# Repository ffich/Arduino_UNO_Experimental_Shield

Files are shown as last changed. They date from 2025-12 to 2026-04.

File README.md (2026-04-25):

# Arduino_UNO_Experimental_Shield
Experimental shield for Arduino UNO form factor boards.

Welcome to the official repository of the **UNO Experimental SHIELD**, an expansion board designed to provide a complete laboratory environment for experimenting, testing, and learning with the Arduino UNO Boards (e.g **UNO Q**).
This shield integrates digital and analog I/O, SPI, I2C, sensors, memory, and diagnostics to create a versatile platform ideal for rapid prototyping, debugging, and education.



---

## 🚀 Key Features

### 🔹 Digital I/O
- SMD LEDs on pins **D2, D3, D6, D7, D8, D9**
- Push buttons on pins **A2, A3**

### 🔹 Analog Inputs
- **Two 100 kΩ trimmers** on analog inputs **A0, A1**  

### 🔹 Serial Communication
- **USB-to-Serial bridge** (CH340)  

### 🔹 CAN Bus
- **CAN transceiver** (TJA1051T3)  
- **120 Ω termination resistor** enabled by jumper  
- Screw terminal output: CANH / CANL

### 🔹 RS-485
- **RS485 transceiver**
- **120 Ω termination resistor** enabled by jumper  
- Screw terminal output: A / B 

### 🔹 I2C Display
- Integrated **SSD1306 OLED display**

### 🔹 I2C Thermometer
- Integrated **TMP102 thermo**  

### 🔹 SPI Memory
- **25LC256 EEPROM** connected to hardware SPI  
- Dedicated Chip Select line

### 🔹 Crypto Chip
- Integrated **ATECC608C**  - 

---

## 📐 Pinout Summary

### Digital I/O
| UNO Pin | Shield Function |
|---|---|
| D2, D3, D6, D7, D8, D9 | LED  |
| A2, A3 | Buttons  |

### Analog
| Pin | Function |
|-----|---|
| A0 | Trimmer 1 |
| A1 | Trimmer 2 |

### Peripherals
| Function | Pin |
|---|-----|
| SPI EEPROM | MOSI / MISO / SCK + CS |
| I2C OLED | SDA / SCL |
| I2C Thermo | SDA / SCL |
| I2C Crypto Chip | SDA / SCL |
| CAN | CAN_TX / CAN_RX |
| RS485 | TX / RX |
| USB-Serial | TX / RX |

The Shield is compatible with both Arduino UNOs with 3V3 and 5V logic (some jumpers allow to adapt the voltage levels).

---

## 🛠️ Project Goals

This shield is intended for:
- Users who want a **complete test environment** for Arduino UNO Boards (e.g. **UNO Q**, **UNO R4**) 
- Makers performing **rapid firmware debugging**  
- Schools, workshops, and educational labs  
- Testing all core firmware interfaces (PWM, ADC, SPI, I2C, CAN, UART)

---

## 📷 Logo

The official project logo is available in the `/assets/logo/` directory.

---

## 📝 License

This project is released under the **MIT License**, unless otherwise specified for hardware files.

---

## 🤝 Contributing

Pull requests and issues are welcome!  
Contributions improving documentation, firmware examples, or hardware design are highly appreciated.

---

## 📫 Contact

For questions or suggestions, open an Issue in the repository or contact the maintainer.

---

Happy experimenting! 🔧✨

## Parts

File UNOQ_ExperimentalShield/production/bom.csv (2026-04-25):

Designator | Footprint | Quantity | Value | LCSC Part #
C1, C2, C3, C4, C5, C6, C7 | 0402 | 7 | 100nF | C155422
CN1 | PinHeader_1x02_P2.54mm_Vertical | 1 | 485 | C5360898
CN2 | USB_C_Receptacle_HRO_TYPE-C-31-M-12 | 1 | USB | C165948
CN3 | TerminalBlock_Phoenix_MPT-0,5-2-2.54_1x02_P2.54mm_Horizontal | 1 | Can | C474920
CN4 | PinHeader_1x04_P2.54mm_Vertical | 1 | Can | C2905435
CN5 | TerminalBlock_Phoenix_MPT-0,5-2-2.54_1x02_P2.54mm_Horizontal | 1 | 485 | C474920
JP1, JP2, JP3, JP4, JP6, JP7, JP8 | PinHeader_1x03_P2.54mm_Vertical | 7 | Jmp | C49257
JP5 | PinHeader_2x02_P2.54mm_Vertical | 1 | Jmp | C32713275
LD1, LD2, LD3, LD4, LD5, LD6 | 0603 | 6 | O1_G | C12624
LD10, LD8 | 0603 | 2 | Tx | C2286
LD11 | 0603 | 1 | 3v3 | C2286
LD12 | 0603 | 1 | 5v | C2286
LD7, LD9 | 0603 | 2 | Rx | C2286
OLED1 | OLED096 | 1 | OLED | C5248080
R1, R2, R3, R4, R5, R7 | 0402 | 6 | 1.5k | C25867
R10, R18, R19, R21, R22, R24, R9 | 0402 | 7 | 10k | C174175
R13, R14 | 0402 | 2 | 5.1k | C25905
R15, R16, R25, R28, R29, R30 | 0402 | 6 | 1k | C140196
R23, R27 | 0603 | 2 | 120 | C177328
R6, R8 | 0603 | 2 | 2.2k
RV1, RV2 | Potentiometer_Bourns_3386P_Vertical | 2 | Tr | C116303
SW1, SW2 | SW_SPST_PTS810 | 2 | Usr1 | C221895
U1 | SO-8_3.9x4.9mm_P1.27mm | 1 | 25LCxxx | C84670
U2 | SOT-563 | 1 | TMP102xxDRL | C99269
U3 | SOIC-8_3.9x4.9mm_P1.27mm | 1 | MAX3485ESA-MS | C7434431
U4 | JEITA_SOIC-8_3.9x4.9mm_P1.27mm | 1 | CH340N | C2977777
U5 | SOIC-8_3.9x4.9mm_P1.27mm | 1 | TJA1051T-3 | C38695
U7 | SOIC-8_3.9x4.9mm_P1.27mm | 1 | ATECC608A-SSHDA | C28975195

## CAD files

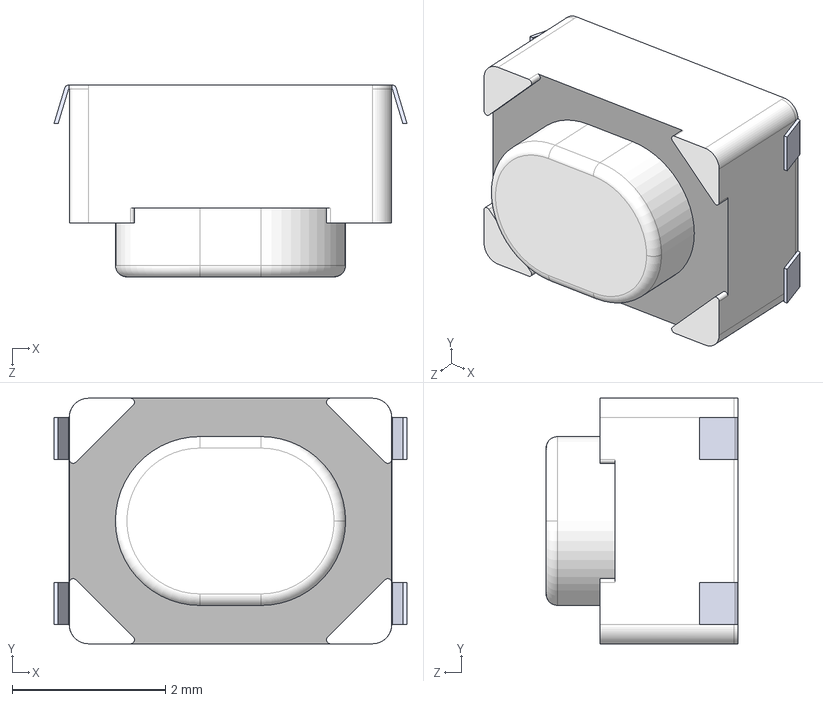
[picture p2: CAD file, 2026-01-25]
UNOQ_ExperimentalShield/3d/PTS810 Series SJS 250.STEP
4.60 x 3.20 x 2.50 mm

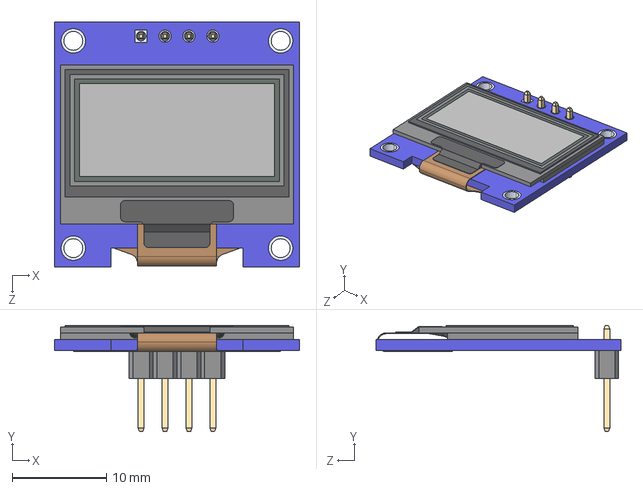
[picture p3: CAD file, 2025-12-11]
UNOQ_ExperimentalShield/footprint/DM-OLED096-636/DM-OLED096-636.step
26.0 x 11.3 x 26.0 mm
DM-OLED096-636_Module
DM-OLED096-636_Panel

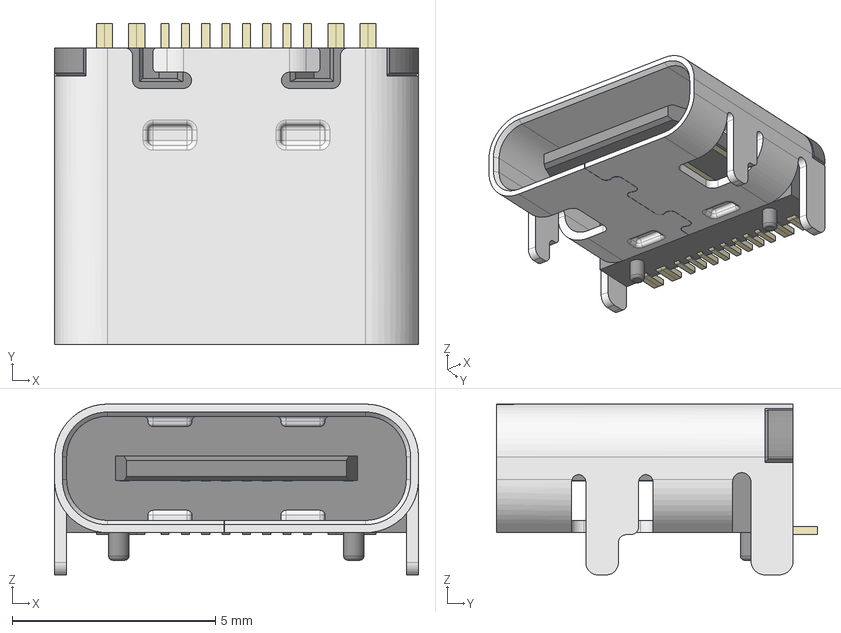
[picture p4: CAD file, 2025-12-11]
UNOQ_ExperimentalShield/3d/HRO_TYPE-C-31-M-12.step
8.95 x 7.90 x 4.20 mm

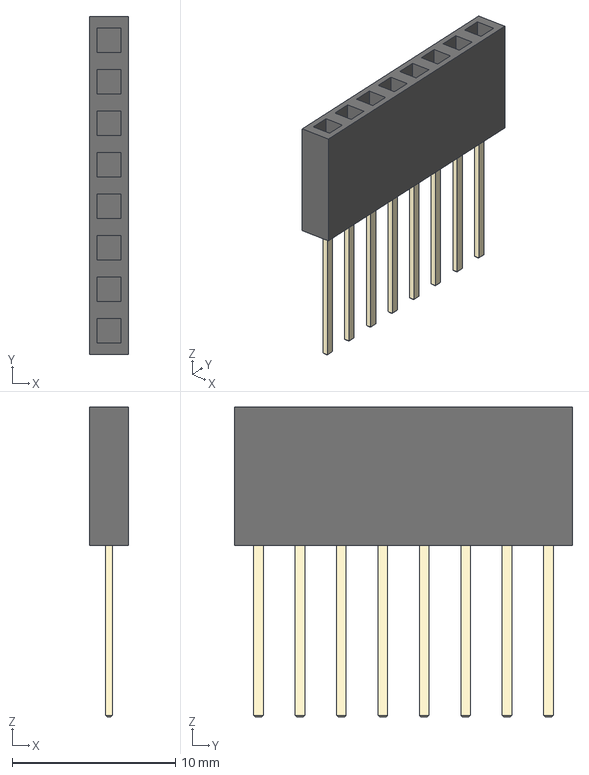
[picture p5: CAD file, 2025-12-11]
UNOQ_ExperimentalShield/3d/Schmartboard 920-0086-01 Headers for Arduino.step
2.40 x 20.7 x 19.0 mm

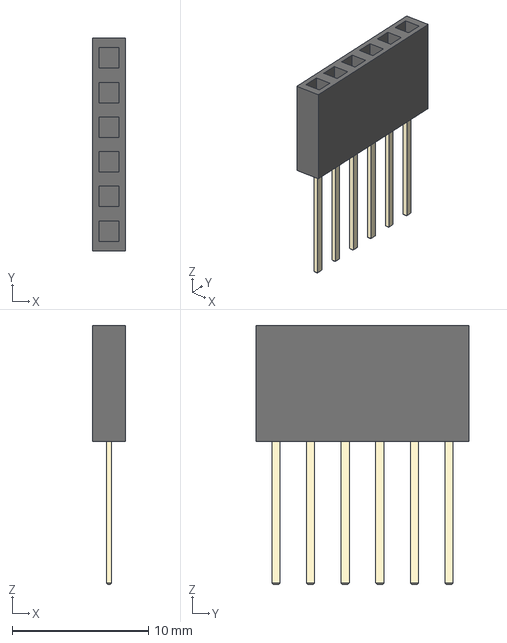
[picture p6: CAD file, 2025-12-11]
UNOQ_ExperimentalShield/3d/Schmartboard 920-0085-01 Headers for Arduino.step
2.40 x 15.6 x 19.0 mm

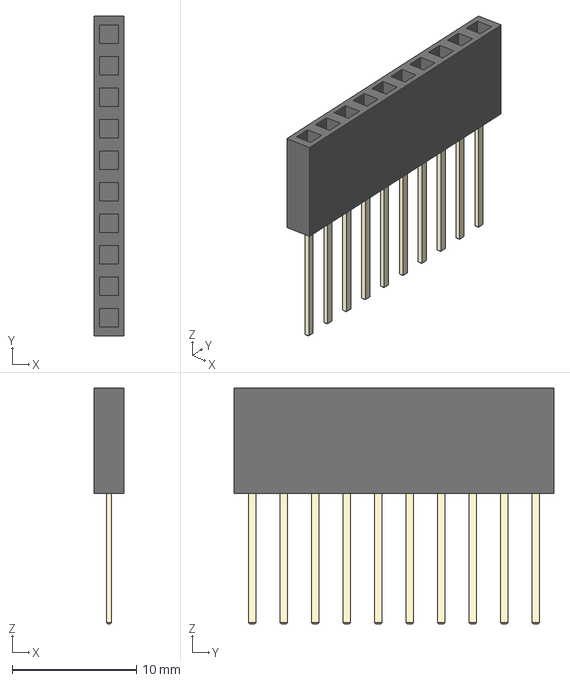
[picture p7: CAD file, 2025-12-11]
UNOQ_ExperimentalShield/3d/Schmartboard 920-0087-01 Headers for Arduino v1.step
2.40 x 25.8 x 19.0 mm

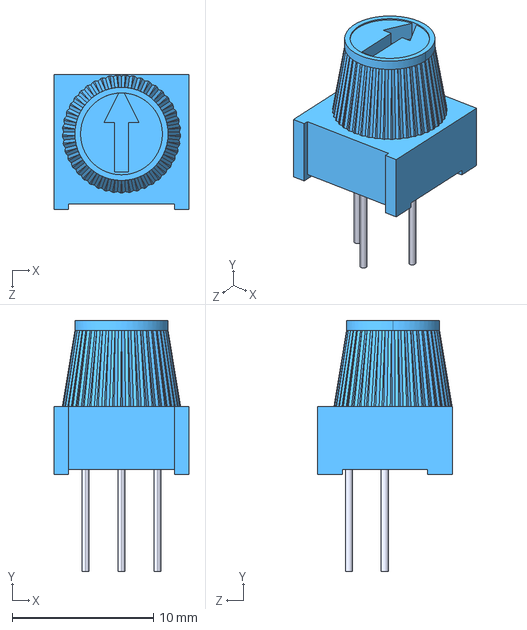
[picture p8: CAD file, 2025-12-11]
UNOQ_ExperimentalShield/3d/3386P-1-104TLF.STEP
9.53 x 17.8 x 9.53 mm

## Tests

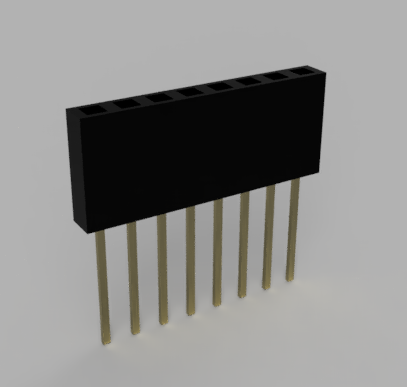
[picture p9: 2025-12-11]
UNOQ_ExperimentalShield/3d/Schmartboard_920-0086-01_Headers_for_Arduino.png

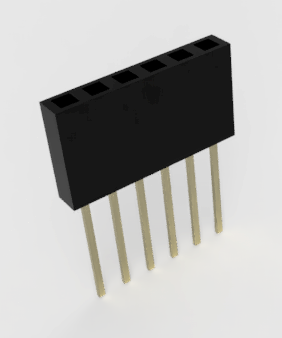
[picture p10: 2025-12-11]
UNOQ_ExperimentalShield/3d/Schmartboard_920-0085-01_Headers_for_Arduino.png

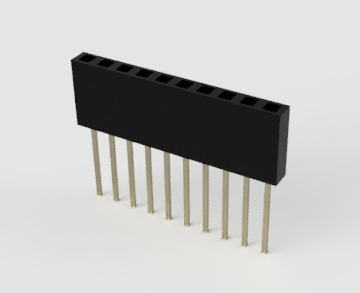
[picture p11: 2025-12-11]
UNOQ_ExperimentalShield/3d/Schmartboard_920-0087-01_Headers_for_Arduino.png

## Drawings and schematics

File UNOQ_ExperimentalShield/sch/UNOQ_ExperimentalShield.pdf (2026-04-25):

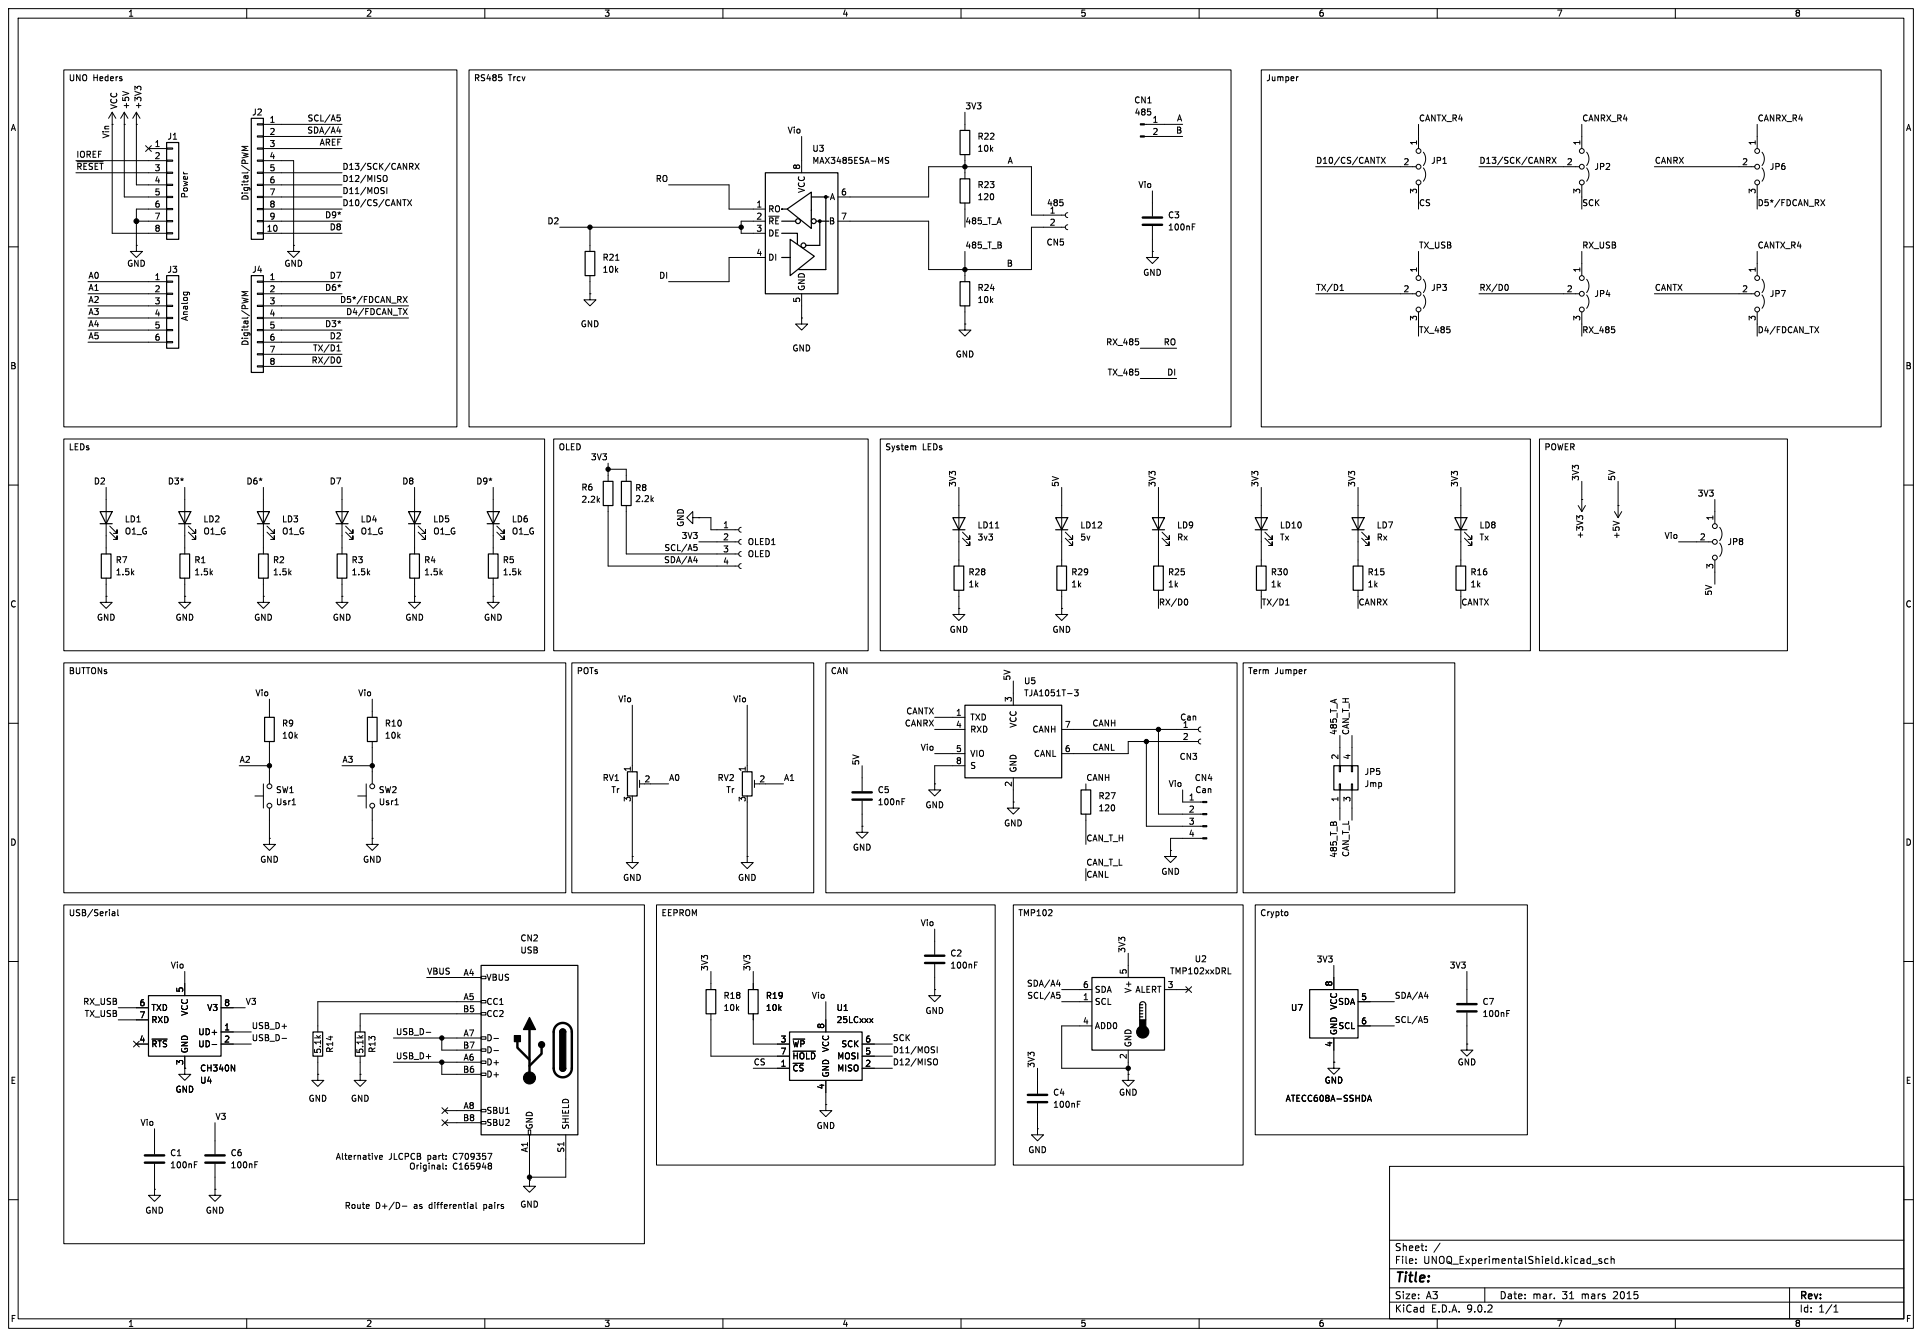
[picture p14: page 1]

3V3 D8 SCL/A5 D9* D13/SCK/CANRX D12/MISO

3 TXD 6 RXD 7 ~{RTS} 4 U4 CH340N GND GND5.1k R14 GND GND

4 SCK 6 MOSI 5 MISO 2 U7 ATECC608A-SSHDA VCC

4 SDA 5 SCL 6 U7 ATECC608A-SSHDA GND

Id: 1/1 Title: File: UNOQ_ExperimentalShield.kicad_sch Sheet: /

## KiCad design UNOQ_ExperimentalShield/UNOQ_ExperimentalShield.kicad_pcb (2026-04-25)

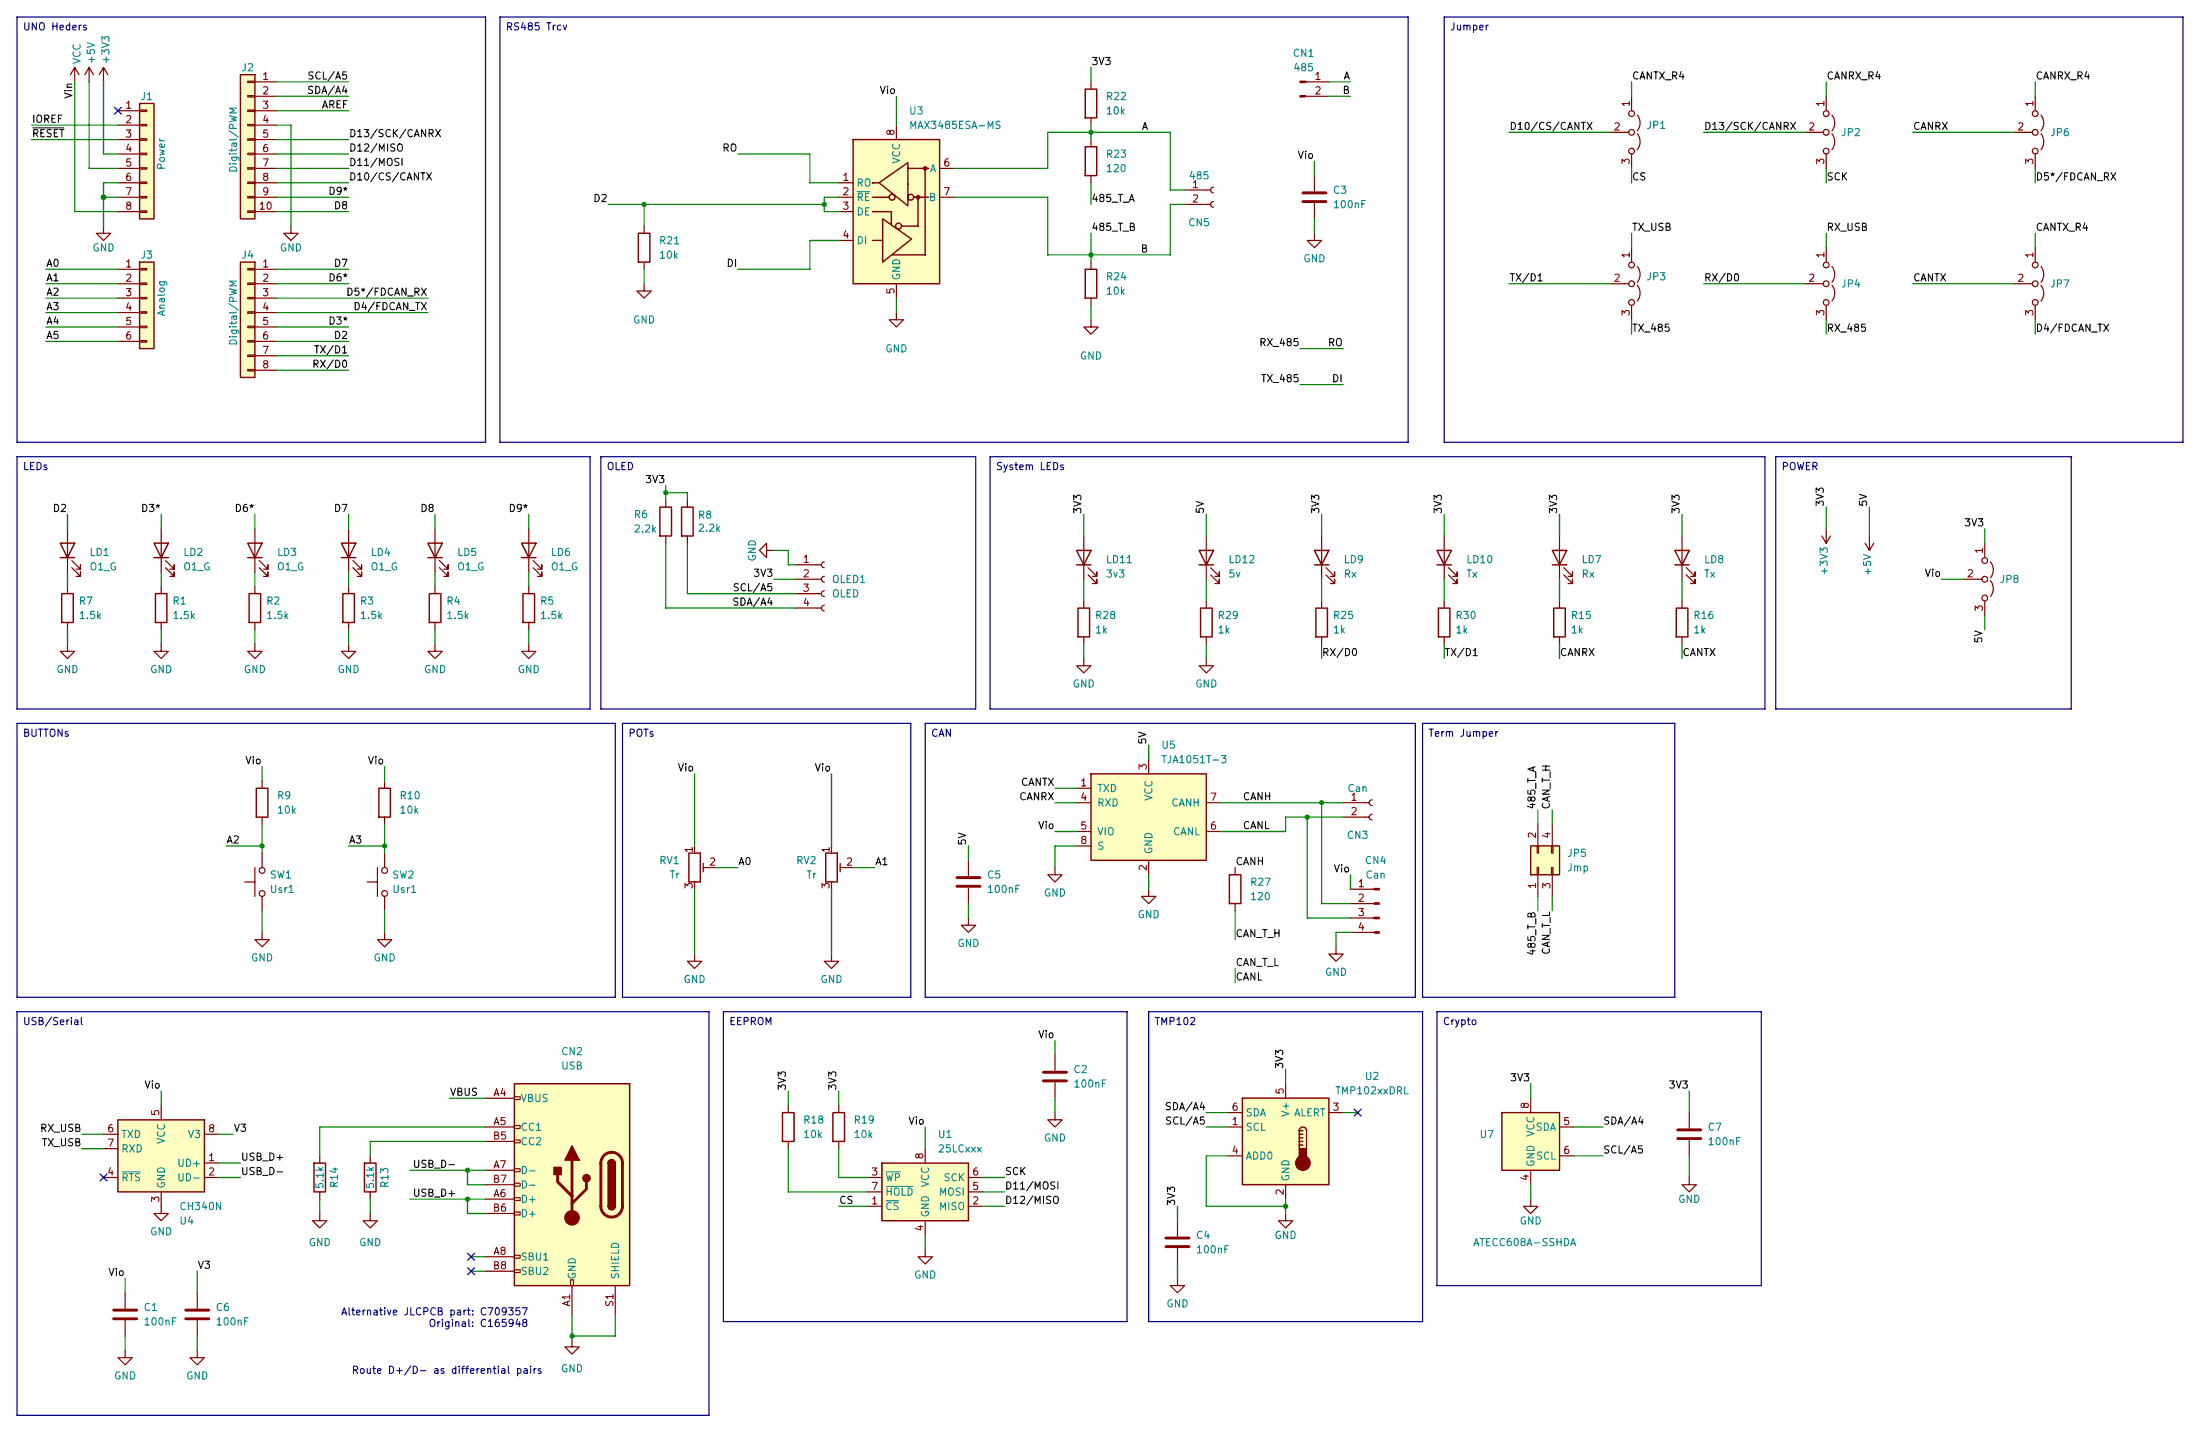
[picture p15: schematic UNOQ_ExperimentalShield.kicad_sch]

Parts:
C1, C2, C3, C4, C5, C6, C7: 100nF; C_0402_1005Metric; LCSC C155422
CN1: 485; PinHeader_1x02_P2.54mm_Vertical; LCSC C5360898
CN2: USB; USB_C_Receptacle_HRO_TYPE-C-31-M-12; LCSC C165948
CN3: Can; TerminalBlock_Phoenix_MPT-0,5-2-2.54_1x02_P2.54mm_Horizontal; LCSC C474920
CN4: Can; PinHeader_1x04_P2.54mm_Vertical; LCSC C2905435
CN5: 485; TerminalBlock_Phoenix_MPT-0,5-2-2.54_1x02_P2.54mm_Horizontal; LCSC C474920
J1: Power; PinHeader_1x08_P2.54mm_Vertical; LCSC C32713274
J2: Digital/PWM; PinHeader_1x10_P2.54mm_Vertical; LCSC C57369
J3: Analog; PinHeader_1x06_P2.54mm_Vertical; LCSC C32713272
J4: Digital/PWM; PinHeader_1x08_P2.54mm_Vertical; LCSC C32713274
JP1, JP2, JP3, JP4, JP6, JP7, JP8: Jmp; PinHeader_1x03_P2.54mm_Vertical; LCSC C49257
JP5: Jmp; PinHeader_2x02_P2.54mm_Vertical; LCSC C32713275
LD1, LD2, LD3, LD4, LD5, LD6: O1_G; LED_0603_1608Metric; LCSC C12624
LD7, LD9: Rx; LED_0603_1608Metric; LCSC C2286
LD8, LD10: Tx; LED_0603_1608Metric; LCSC C2286
LD11: 3v3; LED_0603_1608Metric; LCSC C2286
LD12: 5v; LED_0603_1608Metric; LCSC C2286
OLED1: OLED; OLED096; LCSC C5248080
R1, R2, R3, R4, R5, R7: 1.5k; R_0402_1005Metric; LCSC C25867
R6, R8: 2.2k; R_0603_1608Metric
R9, R10, R18, R19, R21, R22, R24: 10k; R_0402_1005Metric; LCSC C174175
R13, R14: 5.1k; R_0402_1005Metric; LCSC C25905
R15, R16, R25, R28, R29, R30: 1k; R_0402_1005Metric; LCSC C140196
R23, R27: 120; R_0603_1608Metric; LCSC C177328
RV1, RV2: Tr; Potentiometer_Bourns_3386P_Vertical; LCSC C116303
SW1, SW2: Usr1; SW_SPST_PTS810; LCSC C221895
U1: 25LCxxx; SO-8_3.9x4.9mm_P1.27mm; LCSC C84670
U2: TMP102xxDRL; SOT-563; LCSC C99269
U3: MAX3485ESA-MS; SOIC-8_3.9x4.9mm_P1.27mm; LCSC C7434431
U4: CH340N; JEITA_SOIC-8_3.9x4.9mm_P1.27mm; LCSC C2977777
U5: TJA1051T-3; SOIC-8_3.9x4.9mm_P1.27mm; LCSC C38695
U7: ATECC608A-SSHDA; SOIC-8_3.9x4.9mm_P1.27mm; LCSC C28975195

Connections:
+3V3: C4.1, C7.1, J1.4, JP8.1 (A), LD7.2 (A), LD8.2 (A), LD9.2 (A), LD10.2 (A), LD11.2 (A), OLED1.2, R6.1, R8.1, R18.1, R19.1, R22.1, U2.5 (V+), U7.8 (VCC)
+5V: C5.1, J1.5, JP8.3 (B), LD12.2 (A), U5.3 (VCC)
/485_T_A: JP5.2, R23.2
/485_T_B: CN1.2, CN5.2, JP5.1, R24.1, U3.7 (B)
/A: CN1.1, CN5.1, R22.2, R23.1, U3.6 (A)
/A0: J3.1, RV1.2
/A1: J3.2, RV2.2
/A2: J3.3, R9.2, SW1.2
/A3: J3.4, R10.2, SW2.2
/A4: J3.5
/A5: J3.6
/AREF: J2.3
/CANH: CN3.1, CN4.2, R27.1, U5.7 (CANH)
/CANL: CN3.2, CN4.3, JP5.3, U5.6 (CANL)
/CANRX: JP6.2 (C), R15.2, U5.4 (RXD)
/CANRX_R4: JP2.1 (A), JP6.1 (A)
/CANTX: JP7.2 (C), R16.2, U5.1 (TXD)
/CANTX_R4: JP1.1 (A), JP7.1 (A)
/CAN_T_H: JP5.4, R27.2
/CS: JP1.3 (B), U1.1 (~CS)
/D2: J4.6, LD1.2 (A), R21.1, U3.2 (~RE), U3.3 (DE)
/D3*: J4.5, LD2.2 (A)
/D4/FDCAN_TX: J4.4, JP7.3 (B)
/D5*/FDCAN_RX: J4.3, JP6.3 (B)
/D6*: J4.2, LD3.2 (A)
/D7: J4.1, LD4.2 (A)
/D8: J2.10, LD5.2 (A)
/D9*: J2.9, LD6.2 (A)
/D10/CS/CANTX: J2.8, JP1.2 (C)
/D11/MOSI: J2.7, U1.5 (MOSI)
/D12/MISO: J2.6, U1.2 (MISO)
/D13/SCK/CANRX: J2.5, JP2.2 (C)
/DI: JP3.3 (B), U3.4 (DI)
/IOREF: J1.2
/RO: JP4.3 (B), U3.1 (RO)
/RX_USB: JP4.1 (A), U4.6 (TXD)
/RX/D0: J4.8, JP4.2 (C), R25.2
/SCK: JP2.3 (B), U1.6 (SCK)
/SCL/A5: J2.1, OLED1.3, R8.2, U2.1 (SCL), U7.6 (SCL)
/SDA/A4: J2.2, OLED1.4, R6.2, U2.6 (SDA), U7.5 (SDA)
/TX_USB: JP3.1 (A), U4.7 (RXD)
/TX/D1: J4.7, JP3.2 (C), R30.2
/USB_D+: CN2.A6 (D+), CN2.B6 (D+), U4.1 (UD+)
/USB_D-: CN2.A7 (D-), CN2.B7 (D-), U4.2 (UD-)
/V3: C6.1, U4.8 (V3)
/VBUS: CN2.A4 (VBUS), CN2.A9 (VBUS), CN2.B4 (VBUS), CN2.B9 (VBUS)
/Vio: C1.1, C2.1, C3.1, CN4.1, JP8.2 (C), R9.1, R10.1, RV1.1, RV2.1, U1.8 (VCC), U3.8 (VCC), U4.5 (VCC), U5.5 (VIO)
/~RESET: J1.3
GND: C1.2, C2.2, C3.2, C4.2, C5.2, C6.2, C7.2, CN2.A1 (GND), CN2.A12 (GND), CN2.B1 (GND), CN2.B12 (GND), CN2.S1 (SHIELD), CN4.4, J1.6, J1.7, J2.4, OLED1.1, R1.2, R2.2, R3.2, R4.2, R5.2, R7.2, R13.1, R14.1, R21.2, R24.2, R28.2, R29.2, RV1.3, RV2.3, SW1.1, SW2.1, U1.4 (GND), U2.2 (GND), U2.4 (ADD0), U3.5 (GND), U4.3 (GND), U5.2 (GND), U5.8 (S), U7.4 (GND)
unnamed: CN2.A5 (CC1), R14.2
unnamed: CN2.B5 (CC2), R13.2
unnamed: LD1.1 (K), R7.1
unnamed: LD2.1 (K), R1.1
unnamed: LD3.1 (K), R2.1
unnamed: LD4.1 (K), R3.1
unnamed: LD5.1 (K), R4.1
unnamed: LD6.1 (K), R5.1
unnamed: LD7.1 (K), R15.1
unnamed: LD8.1 (K), R16.1
unnamed: LD9.1 (K), R25.1
unnamed: LD10.1 (K), R30.1
unnamed: LD11.1 (K), R28.1
unnamed: LD12.1 (K), R29.1
unnamed: R18.2, U1.7 (~HOLD)
unnamed: R19.2, U1.3 (~WP)
VCC: J1.8

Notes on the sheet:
Route D+/D- as differential pairs
Alternative JLCPCB part: C709357 Original: C165948
System LEDs
LEDs
TMP102
Term Jumper
CAN
OLED
EEPROM
Crypto
RS485 Trcv
Jumper
POTs
POWER
UNO Heders
USB/Serial
BUTTONs

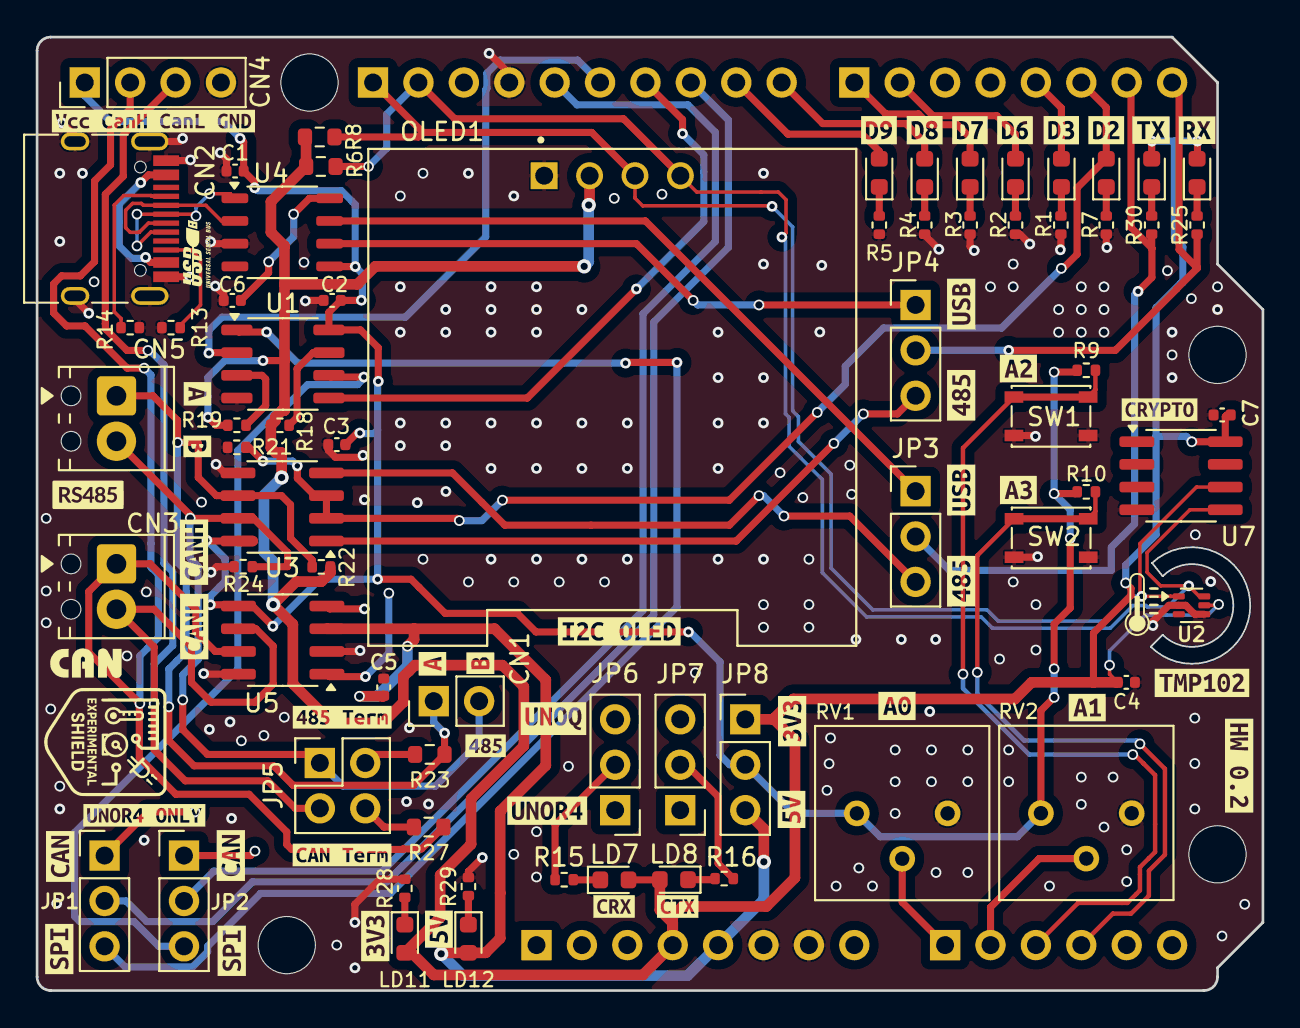
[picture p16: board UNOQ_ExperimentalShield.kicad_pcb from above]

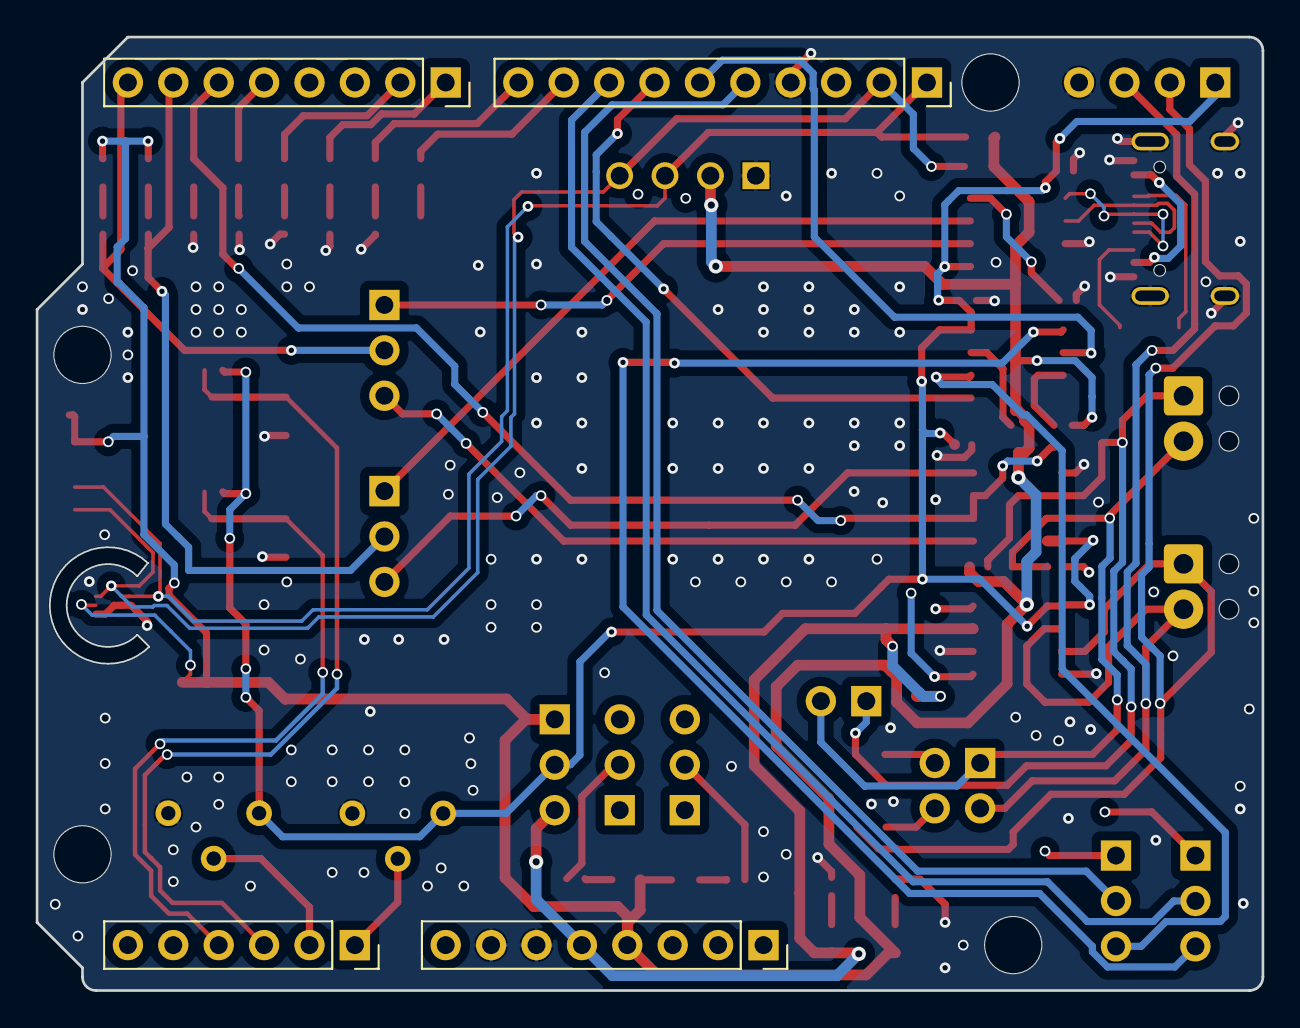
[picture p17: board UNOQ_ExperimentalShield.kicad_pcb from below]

Board: 4 copper layers, 68.6 x 53.3 mm, 119 parts (4 on the bottom side), 60 nets.

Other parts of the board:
MH1, MH2, MH3, MH4: MountingHole_3.2mm
kibuzzard-69DFD334: G***; kibuzzard-69DFD334
kibuzzard-69E2216E: G***; kibuzzard-69E2216E
kibuzzard-69E22173: G***; kibuzzard-69E22173
kibuzzard-69E66319: G***; kibuzzard-69E66319
kibuzzard-69ECB5A8: G***; kibuzzard-69ECB5A8
kibuzzard-69ECB57B: G***; kibuzzard-69ECB57B
kibuzzard-69ECB59B: G***; kibuzzard-69ECB59B
kibuzzard-69ECB574: G***; kibuzzard-69ECB574
kibuzzard-693AADEF: G***; kibuzzard-693AADEF
kibuzzard-697C8D0C: G***; kibuzzard-697C8D0C
kibuzzard-697C8D01: G***; kibuzzard-697C8D01
kibuzzard-697C896A: G***; kibuzzard-697C896A
kibuzzard-697C897C: G***; kibuzzard-697C897C
kibuzzard-697C8970: G***; kibuzzard-697C8970
kibuzzard-697C8977: G***; kibuzzard-697C8977
kibuzzard-69443E7E: G***; kibuzzard-69443E7E
kibuzzard-69443E38: G***; kibuzzard-69443E38
kibuzzard-69443E67: G***; kibuzzard-69443E67
kibuzzard-69595BB4: G***; kibuzzard-69595BB4
kibuzzard-69595BC0: G***; kibuzzard-69595BC0
kibuzzard-69595C5E: G***; kibuzzard-69595C5E
kibuzzard-69595C8D: G***; kibuzzard-69595C8D
kibuzzard-69595C64: G***; kibuzzard-69595C64
kibuzzard-69595C77: G***; kibuzzard-69595C77
kibuzzard-69595C82: G***; kibuzzard-69595C82
kibuzzard-69595C87: G***; kibuzzard-69595C87
kibuzzard-69595C92: G***; kibuzzard-69595C92
kibuzzard-69595C98: G***; kibuzzard-69595C98
kibuzzard-69595CA1: G***; kibuzzard-69595CA1
kibuzzard-69595CF0: G***; kibuzzard-69595CF0
kibuzzard-69595CF5: G***; kibuzzard-69595CF5
kibuzzard-69595D7B: G***; kibuzzard-69595D7B
kibuzzard-69595D77: G***; kibuzzard-69595D77
kibuzzard-69595D81: G***; kibuzzard-69595D81
kibuzzard-69764F79: G***; kibuzzard-69764F79
kibuzzard-69878B44: G***; kibuzzard-69878B44
kibuzzard-698784C3: G***; kibuzzard-698784C3
kibuzzard-698784D4: G***; kibuzzard-698784D4
kibuzzard-6976550D: G***; kibuzzard-6976550D
kibuzzard-6987886F: G***; kibuzzard-6987886F
kibuzzard-6987894B: G***; kibuzzard-6987894B
kibuzzard-69765506: G***; kibuzzard-69765506
kibuzzard-69878868: G***; kibuzzard-69878868

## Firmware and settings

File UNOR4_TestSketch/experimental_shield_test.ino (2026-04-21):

/*
 * experimental_shield_test.ino
 *
 * Full test suite for the Arduino UNO Experimental Shield on Arduino UNO R4.
 * 
 * Manual Mode: Select test using buttons D16, D17, D18, D19.
 * 
 * Logic:
 * 1. LED Chase (Startup)
 * 2. Dashboard (Idle) - Live sensors, wait for button
 * 3. Prep - Show Jumper warnings, wait for button
 * 4. Run - Execute test at 1s rate until button pressed
 *
 * Libraries: Adafruit SSD1306, Adafruit GFX, Arduino_CAN, SPI, Wire
 */

#include <Wire.h>
#include <SPI.h>
#include <Adafruit_GFX.h>
#include <Adafruit_SSD1306.h>
#include <Arduino_CAN.h>

// ─── PIN DEFINITIONS ────────────────────────────────────────────────────────
const int LED_PINS[] = {2, 3, 6, 7, 8, 9};
const int NUM_LEDS   = 6;

// Buttons connected to Analog Pins (A2=D16, A3=D17)
const int BTN_PINS[] = {16, 17}; 
const int NUM_BTNS   = 2;

const int PIN_POT1   = A0;
const int PIN_POT2   = A1;
const int PIN_RS485_CTRL = 5; // DE/RE
const int PIN_EEPROM_CS  = 10;

// ─── CONSTANTS ──────────────────────────────────────────────────────────────
#define SCREEN_WIDTH 128
#define SCREEN_HEIGHT 64
#define OLED_RESET    -1
#define OLED_ADDR     0x3C
#define TMP102_ADDR   0x48

// ─── OBJECTS ────────────────────────────────────────────────────────────────
Adafruit_SSD1306 display(SCREEN_WIDTH, SCREEN_HEIGHT, &Wire, OLED_RESET);

// ─── STATE ──────────────────────────────────────────────────────────────────
enum AppState {
  PHASE_LEDS,
  PHASE_DASHBOARD,
  PHASE_TEST_PREP,
  PHASE_TEST_RUN
};

AppState currentState = PHASE_DASHBOARD;
int activeTestIndex = 0; // 0=EEPROM, 1=CAN, 2=RS485, 3=USB, 4=SUPERCAR, 5=GAME
unsigned long lastUpdate = 0;
const char* testNames[] = {"EEPROM", "CAN", "RS485", "USB-CH340", "SUPERCAR", "GAME"};
const int NUM_TESTS = 6;

// PERSISTENT DATA
int sessionHighScore = 0;

// ─── HELPERS ────────────────────────────────────────────────────────────────

// Read TMP102 Temperature
float readTMP102() {
  Wire.beginTransmission(TMP102_ADDR);
  Wire.write(0x00);
  Wire.endTransmission();
  if (Wire.requestFrom(TMP102_ADDR, 2) == 2) {
    uint8_t msb = Wire.read();
    uint8_t lsb = Wire.read();
    int tempSum = ((msb << 8) | lsb) >> 4;
    return tempSum * 0.0625;
  }
  return 0.0;
}

void drawHeader(const char* title) {
  display.clearDisplay();
  display.setTextSize(1);
  display.setTextColor(SSD1306_WHITE);
  display.setCursor(0,0);
  display.println(title);
  display.drawFastHLine(0, 9, 128, SSD1306_WHITE);
}

// Robust button polling (D16-D19)
int getButtonPressed() {
  for (int i = 0; i < NUM_BTNS; i++) {
    pinMode(BTN_PINS[i], INPUT_PULLUP);
    if (digitalRead(BTN_PINS[i]) == LOW) {
      delay(20);
      if (digitalRead(BTN_PINS[i]) == LOW) {
        while(digitalRead(BTN_PINS[i]) == LOW); // Wait release
        return i + 1;
      }
    }
  }
  return 0;
}

void getSensorString(char* buf, int size, const char* label) {
  int p1 = analogRead(PIN_POT1);
  int p2 = analogRead(PIN_POT2);
  float t = readTMP102();
  char tStr[10];
  dtostrf(t, 4, 1, tStr);
  snprintf(buf, size, "%s: P1=%d P2=%d T=%s", label, p1, p2, tStr);
}

// ─── SETUP ──────────────────────────────────────────────────────────────────
void setup() {
  Serial.begin(115200);
  Serial1.begin(9600);
  Wire.begin();
  if(!display.begin(SSD1306_SWITCHCAPVCC, OLED_ADDR)) {
    Serial.println(F("OLED fail"));
  }
  display.clearDisplay();
  display.display();

  pinMode(PIN_RS485_CTRL, OUTPUT);
  digitalWrite(PIN_RS485_CTRL, LOW);
  pinMode(PIN_EEPROM_CS, OUTPUT);
  digitalWrite(PIN_EEPROM_CS, HIGH);

  // Initialize LED pins
  for (int i = 0; i < NUM_LEDS; i++) {
    pinMode(LED_PINS[i], OUTPUT);
    digitalWrite(LED_PINS[i], LOW);
  }
}

// ─── MAIN LOOP ──────────────────────────────────────────────────────────────
void loop() {
  unsigned long now = millis();

  switch (currentState) {
    
    case PHASE_LEDS: {
      drawHeader("UNO-EXP MANUAL");
      display.setCursor(0, 20);
      display.println("Phase 1: LED Chase");
      display.display();
      for (int i = 0; i < NUM_LEDS; i++) {
        pinMode(LED_PINS[i], OUTPUT);
        digitalWrite(LED_PINS[i], HIGH);
        delay(500);
        digitalWrite(LED_PINS[i], LOW);
      }
      currentState = PHASE_DASHBOARD;
      break;
    }

    case PHASE_DASHBOARD: {
      if (now - lastUpdate >= 100) {
        lastUpdate = now;
        drawHeader("DASHBOARD (IDLE)");
        int p1 = analogRead(PIN_POT1);
        int p2 = analogRead(PIN_POT2);
        float t = readTMP102();
        display.setCursor(0, 15);
        display.print("POT1: "); display.println(p1);
        display.print("POT2: "); display.println(p2);
        display.print("TEMP: "); display.print(t); display.println(" C");
        display.setCursor(0, 44);
        display.print("> "); display.println(testNames[activeTestIndex]);
        display.println("B1:Cycle  B2:Select");
        display.display();
      }

      int btn = getButtonPressed();
      if (btn == 1) { // D16 - Cycle
        activeTestIndex = (activeTestIndex + 1) % NUM_TESTS;
      } else if (btn == 2) { // D17 - Select
        currentState = PHASE_TEST_PREP;
      }
      break;
    }

    case PHASE_TEST_PREP: {
      drawHeader("TEST PREP");
      display.setCursor(0, 15);
      display.print("Test: "); display.println(testNames[activeTestIndex]);
      display.setCursor(0, 28);
      if (activeTestIndex == 0) display.println("SET JP2 -> CS");
      if (activeTestIndex == 1) display.println("SET JP1,2 -> CAN");
      if (activeTestIndex == 2) display.println("SET JP3,4 -> RS485");
      if (activeTestIndex == 3) display.println("CHECK SHIELD USB");
      if (activeTestIndex == 4) display.println("OBSERVE LEDS");
      if (activeTestIndex == 5) display.println("D16:L  D17:R");
      
      display.setCursor(0, 55);
      display.println("Press ANY to start");
      display.display();

      if (getButtonPressed() > 0) {
        if (activeTestIndex == 1) CAN.begin(CanBitRate::BR_500k);
        if (activeTestIndex == 0) SPI.begin();
        currentState = PHASE_TEST_RUN;
      }
      break;
    }

    case PHASE_TEST_RUN: {
      static unsigned long holdStart = 0;
      bool isAnyBtnDown = (digitalRead(BTN_PINS[0]) == LOW || digitalRead(BTN_PINS[1]) == LOW);

      // Standard tests update (1s)
      if (activeTestIndex < 4 && (now - lastUpdate >= 1000)) {
        lastUpdate = now;
        char data[100];
        static uint8_t testVal = 0x42;
        testVal = (testVal == 0x42) ? 0xA5 : 0x42;
        
        if (activeTestIndex == 0) { // EEPROM
           digitalWrite(PIN_EEPROM_CS, LOW); SPI.transfer(0x06); digitalWrite(PIN_EEPROM_CS, HIGH); delay(1);
           digitalWrite(PIN_EEPROM_CS, LOW); SPI.transfer(0x02); SPI.transfer(0x00); SPI.transfer(0x00); SPI.transfer(testVal); digitalWrite(PIN_EEPROM_CS, HIGH);
           delay(10);
           digitalWrite(PIN_EEPROM_CS, LOW); SPI.transfer(0x03); SPI.transfer(0x00); SPI.transfer(0x00); uint8_t val = SPI.transfer(0x00); digitalWrite(PIN_EEPROM_CS, HIGH);
           drawHeader("EEPROM RUNNING");
           display.setCursor(0, 20);
           display.print("Tgt: 0x"); display.println(testVal, HEX);
           display.print("Read: 0x"); display.println(val, HEX);
           display.println(val == testVal ? "PASS" : "FAIL");
        }
        else if (activeTestIndex == 1) { // CAN
          uint8_t msgData[8];
          snprintf((char*)msgData, 8, "P1:%d", analogRead(PIN_POT1));
          CAN.write(CanMsg(0x10, 8, msgData));
          drawHeader("CAN RUNNING");
          display.setCursor(0,20);
          display.println("TX ID 0x10\nSensor data out");
        }
        else if (activeTestIndex == 2) { // RS485
          getSensorString(data, sizeof(data), "RS485");
          digitalWrite(PIN_RS485_CTRL, HIGH);
          Serial1.println(data);
          Serial1.flush();
          digitalWrite(PIN_RS485_CTRL, LOW);
          drawHeader("RS485 RUNNING");
          display.setCursor(0,20);
          display.println("TX Active\nCheck A/B lines");
        }
        else if (activeTestIndex == 3) { // USB
          getSensorString(data, sizeof(data), "USB");
          Serial1.println(data);
          drawHeader("USB RUNNING");
          display.setCursor(0,20);
          display.println("TX Active\nCheck Shield USB");
        }

        display.setCursor(0, 55);
        display.println("Press ANY to exit");
        display.display();
      }

      // Fast update for SUPERCAR effect (frequency controlled by A0 Pot)
      int scanSpeed = 100;
      if (activeTestIndex == 4) {
        scanSpeed = map(analogRead(PIN_POT1), 0, 1023, 20, 500);
      }

      if (activeTestIndex == 4 && (now - lastUpdate >= scanSpeed)) {
        lastUpdate = now;
        static int pos = 0;
        static int dir = 1;
        
        // Clear all LEDs
        for(int i=0; i<NUM_LEDS; i++) digitalWrite(LED_PINS[i], LOW);
        
        // Scan effect
        digitalWrite(LED_PINS[pos], HIGH);
        pos += dir;
        if(pos >= NUM_LEDS-1) { pos = NUM_LEDS-1; dir = -1; }
        if(pos <= 0) { pos = 0; dir = 1; }
        
        drawHeader("SUPERCAR EFFECT");
        display.setCursor(0,20);
        display.print("Speed: "); display.print(scanSpeed); display.println("ms");
        display.println("Adjust A0 Pot");
        display.setCursor(0, 55);
        display.println("Hold ANY to exit");
        display.display();
      }

      // Fast update for GAME (30ms refresh)
      if (activeTestIndex == 5 && (now - lastUpdate >= 30)) {
        lastUpdate = now;
        static int playerX = 64;
        static float obsX = 64, obsY = 0;
        static float speed = 1.0;
        static int score = 0;
        static bool isDead = false;
        static bool resetNeeded = true;

        if (resetNeeded) {
          playerX = 64; obsX = random(10, 110); obsY = 0; speed = 1.5; score = 0; isDead = false; resetNeeded = false;
        }

        if (!isDead) {
          // Movement - check buttons directly
          pinMode(BTN_PINS[0], INPUT_PULLUP);
          pinMode(BTN_PINS[1], INPUT_PULLUP);
          if (digitalRead(BTN_PINS[0]) == LOW) playerX -= 4;
          if (digitalRead(BTN_PINS[1]) == LOW) playerX += 4;
          playerX = constrain(playerX, 0, 118);

          // Obstacle logic
          obsY += speed;
          if (obsY > 64) {
            obsY = 0;
            obsX = random(5, 120);
            score++;
            speed += 0.05; // Difficulty increase
          }

          // Collision (Player at y=55, h=5, w=10. Obstacle 5x5)
          if (obsY > 50 && obsY < 60 && obsX > playerX - 5 && obsX < playerX + 10) {
            isDead = true;
            if (score > sessionHighScore) sessionHighScore = score;
          }
        }

        display.clearDisplay();
        if (isDead) {
          display.setCursor(35, 15); display.println("GAME OVER");
          display.setCursor(35, 30); display.print("Score: "); display.println(score);
          display.setCursor(20, 50); display.println("Hold ANY to exit");
          
          if (isAnyBtnDown) {
             if (holdStart == 0) holdStart = millis();
             if (millis() - holdStart > 1000) resetNeeded = true; // 1s hold to retry
          } else {
             holdStart = 0;
          }
        } else {
          // Draw Player
          display.fillRect(playerX, 55, 10, 5, SSD1306_WHITE);
          // Draw Obstacle
          display.fillRect((int)obsX, (int)obsY, 5, 5, SSD1306_WHITE);
          // HUD
          display.setCursor(0, 0); display.print("S:"); display.print(score);
          display.setCursor(50, 0); display.println("Hold:Exit");
          display.setCursor(95, 0); display.print("H:"); display.print(sessionHighScore);
        }
        display.display();
      }

      // ─── TEST EXIT LOGIC ──────────────────────────────────────────────────

      if (activeTestIndex >= 4) { // SUPERCAR (4) and GAME (5) use Long Press
        if (isAnyBtnDown) {
          if (holdStart == 0) holdStart = millis();
          if (millis() - holdStart > 2000) { // 2 second hold to exit
            for(int i=0; i<NUM_LEDS; i++) digitalWrite(LED_PINS[i], LOW);
            currentState = PHASE_DASHBOARD;
            holdStart = 0;
          }
        } else {
          holdStart = 0;
        }

        // Periodically update the UI to show hold progress if needed (optional)
        if (activeTestIndex == 4 || activeTestIndex == 5) {
          if (isAnyBtnDown && holdStart != 0) {
             display.fillRect(0, 62, map(millis() - holdStart, 0, 2000, 0, 128), 2, SSD1306_WHITE);
             display.display();
          }
        }
      } 
      else { // Standard tests (0-3) use short press release
        if (getButtonPressed() > 0) {
          for(int i=0; i<NUM_LEDS; i++) digitalWrite(LED_PINS[i], LOW);
          currentState = PHASE_DASHBOARD;
        }
      }
      break;
    }
  }
}

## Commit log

2025-12-11 Added board project.
    [3386P-1-104TLF.STEP, DM-OLED096-636--3DModel-STEP-56544.STEP, DM-OLED096-636.step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]
2025-12-12 added sch and ibom
    [UNOQ_ExperimentalShield.kicad_pcb]
2026-01-08 Some fixes: - Fixed labesl dimension - Fixed resistor values for leds - Fixed OLED footprint - Added HW version
    [UNOQ_ExperimentalShield.kicad_pcb, UNOQ_ExperimentalShield.kicad_sch]
2026-01-25 Some modifications: - TX/RX Led polarity inverted - LM35 has been replaced with TMP102 (I2C Thermo, better and cheaper) - OLED Shape has been fixed - LED Resistors updated to 1k
    [PTS810 Series SJS 250.STEP, UNOQ_ExperimentalShield.kicad_pcb, UNOQ_ExperimentalShield.kicad_sch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]
2026-02-08 final vesion
    [UNOQ_ExperimentalShield.kicad_pcb, UNOQ_ExperimentalShield.kicad_sch, bom.csv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]
2026-04-21 List of changes/fixes: - Buttons reducto 2 and moved to A2, A3 - Fixed TX/RX CAN lines for R4 - Buttons tied to Vio - Pots tied to Vio - Added ATECC608 secure element
    [UNOQ_ExperimentalShield.kicad_pcb, UNOQ_ExperimentalShield.kicad_sch]
2026-04-25 Added unoq (without can) test sketch
    [UNOQ_ExperimentalShield.kicad_pcb, UNOQ_ExperimentalShield.kicad_sch]
2026-04-25 Some updates
    [UNOQ_ExperimentalShield.kicad_pcb, bom.csv, designators.csv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]
